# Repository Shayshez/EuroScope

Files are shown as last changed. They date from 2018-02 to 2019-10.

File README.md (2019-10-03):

# EuroScope MKII - DSO150 Eurorack Conversion Kit
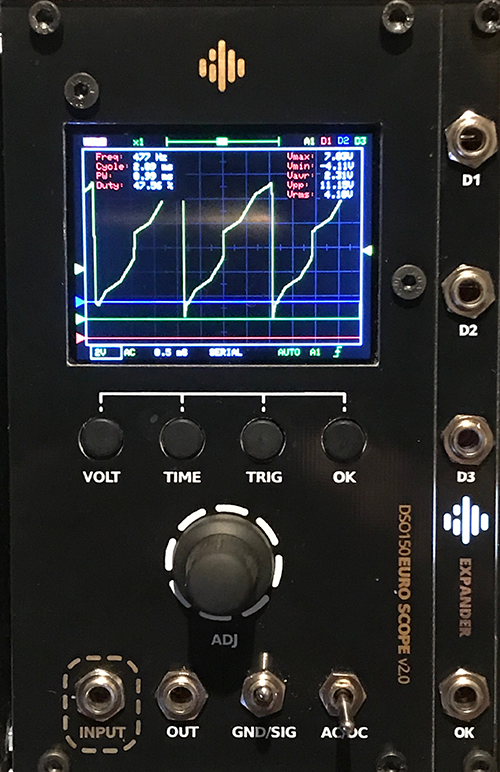
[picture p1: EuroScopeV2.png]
DSO150 EuroScope


[DSO 150](https://www.banggood.com/Orignal-JYE-Tech-DS0150-15001K-DSO-SHELL-DIY-Digital-Oscilloscope-Kit-With-Housing-p-1093865.html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) Is a cheap mini oscilloscope from JYE TECH.

This conversion kit lets you the ability to convert it to Eruorack module and contains two parts:

* 14 Hp Panel
* Conversion Board
* Optional: [Expander 2Hp PCB+Panel](https://pushermanproductions.com/product/plum-audio-dso150-mk2-oscilloscope-expander-2hp-pcb-panel/) - Provides 3 additional digital inputs (Will work only with [Open DSO 150](https://github.com/michar71/Open-DSO-150) Firmware), OK Botton trigger input and Trigger led.

This is an easy DIY project, just follow the [Build guide](EuroScope_mk2_v2.2-Build_Guide.pdf) (PDF File) I'll recommend to download it to your computer.
(You can find the BOM in the build guide).

* Assemblong Videos Playlist: https://www.youtube.com/watch?v=Akz4jSZyOQc&list=PL2KBIbSMnGOh_Mu7Z_c3bYFIhDCGHZpcL

___________________________________________________
## Alternative Firmware:
There is alternative firmware to DSO150 that add lots of new features, more info at:
[Open DSO 150](https://github.com/michar71/Open-DSO-150)
___________________________________________________
## Which is the right DSO150 DIY Kit?
I checked few sources for the DSO150 kits, only the ones that come from [Banggood](https://www.banggood.com/Orignal-JYE-Tech-DS0150-15001K-DSO-SHELL-DIY-Digital-Oscilloscope-Kit-With-Housing-p-1093865.html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) was original 2017 version.

Other versions was less accurate and with a lots of ground noises.
If you’re not buying the banggood version you need to find 2017 version and pay attention to (see picture):
1. Trimmers location.
2. Cut in the main PCB for trimmers access.
3. Only 3 electrolytic capacitors in the analog board (not 5).
4. Sticker with Barcode and Serial Number.
5. Silk screen that says it’s 2017 version... 

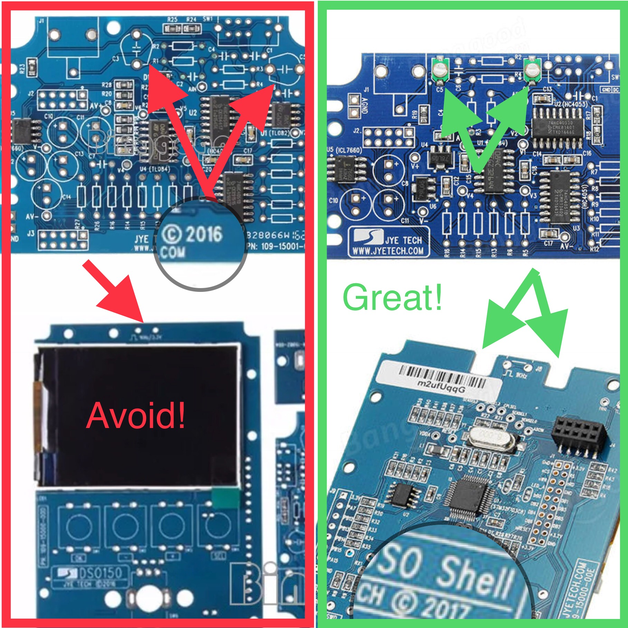
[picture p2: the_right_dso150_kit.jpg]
the right DSO150 DIY Kit


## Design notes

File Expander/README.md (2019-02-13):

# Expander For EuroScope

Adds additional Buffered inputs:
- 3 Digital Inputs D1, D2, D3 ([Open DSO 150](https://github.com/michar71/Open-DSO-150) Firmware is required).
- OK button trigger input.
- Also, brings the DSO150 Trigger led indicator to front.

### Expander BOM:

|Q|Part|Value|Reference|
|-|----|-----|---|
|1|Assembled EuroScope|Expander will work with all versions|[Pusherman](https://pushermanproductions.com/product/dso150-mk2-oscilloscope-eurorack-conversion-kit-14hp-pcb-panel/)|
|1|Expander PCB&Panel||[Pusherman](https://pushermanproductions.com/product/plum-audio-dso150-mk2-oscilloscope-expander-2hp-pcb-panel/)|
|4|Resistor 0603|100k|R1, R2, R3, R4|
|1|Resistor 0603|1K|R5 (For Led Brightness)|
|4|NPN Transistor| MMBT3904|T1, T2, T3, T4|
|1|LED 1206|Any colour you like...|LED1|
|4|Jack PJ398SM|"Thonkiconn"|J2, J3, J4, J5|
|1|Male Pin headers 2.54| 1 row of 7 Pins| J1|

**To connect between Boards:**

|Q|Part|Value|Reference|
|-|----|-----|---|
|1|Male Pin headers 2.54| 1 row of 8 Pins|**DSO150 Main Board:** J9 (For Connection with Expander)|
|1|Male Pin headers 2.54| 1 row of 4 Pins|**DSO150 Main Board:** J3 (SWD - To Update the Firmware)
|7|Feamle to Feamle Jumper Wire|To connect between Boards||
|1|Male to Male Jumper Wire|To connect between Boards|| 

**How To Build?**
1. Build the Expander... Solder all components in place and assemble the panel.
2. Connect the Expander:

|Expander J1|DSO 150|
|---|---|
|3.3V|3.3V @J9|
|PB13|PB13 @J9|
|PB14|PB14 @J9|
|PB15|PB15 @J9|
|GND|GND @J9|

Cut Male to Male Jumper wire into two parts and solder to DSO150:

|Expander J1|DSO 150|
|---|---|
|OK|Top Right Pin of OK Button|
|LED|Remove R14 and solder this wire to top pad of R14|

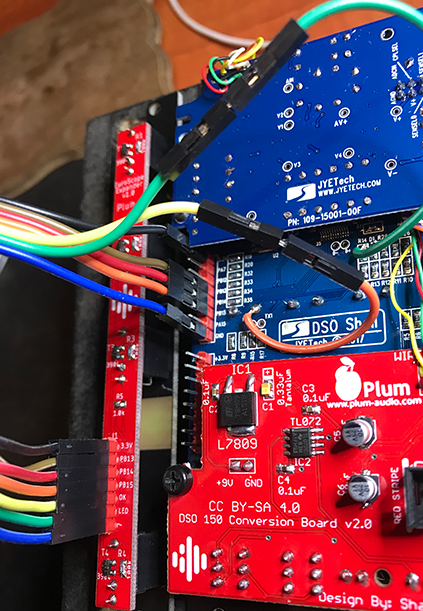
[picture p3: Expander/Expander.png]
Expander

___________________________________________________________________________
# Firmware Update:

I'm using ST-LINK V2 with ST-LINK Utility software on Windows Environment.
You can find hex file in this repo ([here](Firmware%20-%20Open%20DSO150)) 

Connect the programer to DSO150:

|ST-LINK JTAG Port|DSO 150 SWD Port|
|---|---|
|Pin 1|3.3V @J3|
|Pin 3|GND @J3|
|Pin 7|DIO @J3|
|Pin 9|CLK @J3|

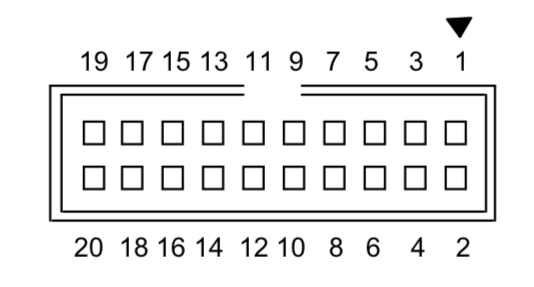
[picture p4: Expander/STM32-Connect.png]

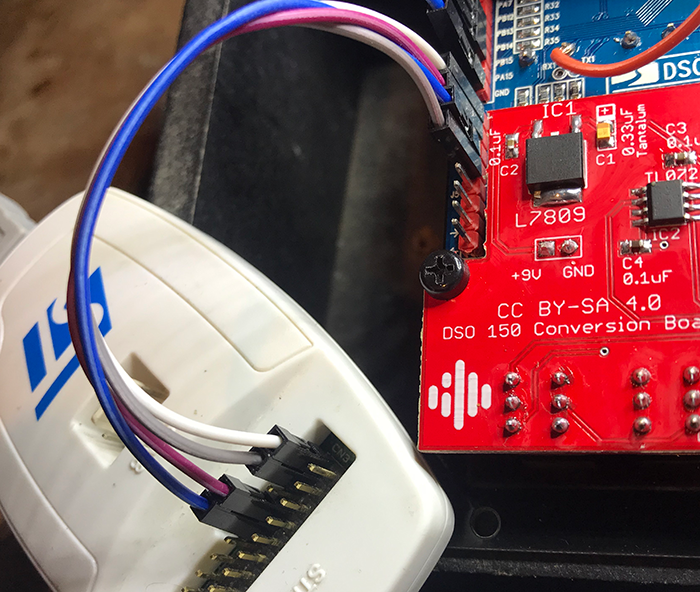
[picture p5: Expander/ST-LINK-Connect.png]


***For next steps you need to connect your EuroScope to power source.**

**With ST-LINK Utility Software:**
1. Go to Target->Settings and choose SWD Port, Frequency = 4.0 MHz, After you click "OK" the programer should connect to DSO150 automatically.
2. Go to Target->Program & Verify, Browse and select new firmware [hex file](Firmware%20-%20Open%20DSO150) and hit Start
3. After the Flash process finished, restart EuroScope and hold "OK" button during boot up.

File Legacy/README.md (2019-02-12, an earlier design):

# DSO150 Eurorack Conversion Kit
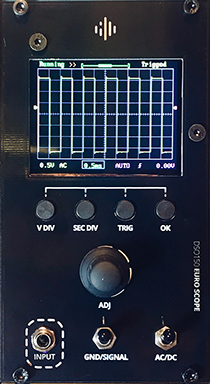
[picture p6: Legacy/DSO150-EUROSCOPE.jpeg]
DSO150 EuroScope


[DSO 150](https://www.banggood.com/Orignal-JYE-Tech-DS0150-15001K-DSO-SHELL-DIY-Digital-Oscilloscope-Kit-With-Housing-p-1093865.html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) Is a cheap mini oscilloscope from JYE TECH.

This conversion kit lets you the ability to convert it to Eruorack module and contains two parts:

* 14 Hp Panel
* Conversion Board

This is an easy DIY project, just follow the [Build guide](https://github.com/Shayshez/DSO150-Euro-Scope/blob/master/DSO-150-Eurorack-Conversion-Kit-v1.pdf).
___________________________________________________
## Bill Of Materials:
Q|Part/Value|Source
-|----------|------
1|DSO150 Eurorack panel|[Pusherman](https://pushermanproductions.com/product/dso150-oscilloscope-eurorack-conversion-kit-14hp-pcb-panel/)
1|DSO150 Conversion Board|[Pusherman](https://pushermanproductions.com/product/dso150-oscilloscope-eurorack-conversion-kit-14hp-pcb-panel/)
1|Original Dso150 (15001K) DIY KIT|[Banggood](https://www.banggood.com/Orignal-JYE-Tech-DS0150-15001K-DSO-SHELL-DIY-Digital-Oscilloscope-Kit-With-Housing-p-1093865.html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)
1|L7809CV – 9v Voltage Regulator|[Tayda](https://www.taydaelectronics.com/l7809cv-l7809-7809-voltage-regulator-ic-9v-1-5a.html)
1|0.33uF – Tantalum Capacitor|[Tayda](https://www.taydaelectronics.com/capacitors/tantalum-capacitors/0-33uf-50v-radial-tantalum-capacitor.html)
1|0.1uF – Ceramic Capacitor|[Tayda](https://www.taydaelectronics.com/capacitors/ceramic-disc-capacitors/10-x-0-1uf-50v-ceramic-disc-capacitor-pkg-of-10.html)
1|2X1 Male Pin Headers|[Tayda](https://www.taydaelectronics.com/connectors-sockets/pin-headers/40-pin-2-54-mm-single-row-pin-header-strip.html)
1|10 Pin Eurorack Power Socket|[Tayda](https://www.taydaelectronics.com/connectors-sockets/box-header-connectors/10-pin-box-header-connector-2-54mm.html)
2|3M - 6mm Standoffs (Spacers) + 2 3M Screws|[AliExpress](https://www.aliexpress.com/item/180Pcs-set-M3-L-6mm-M-F-Black-Spacing-Screw-Plastic-For-PCB-Motherboard-Fixed-Nylon/32834701711.html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,searchweb201602_1_10065_10068_10344_10342_10343_103)
2|3M – 12mm-16mm Black Screws|[AliExpress](https://www.aliexpress.com/item/Free-Shipping-100pcs-M3x8-mm-M3-8-mm-flat-head-countersunk-head-black-grade-10-9/32421673207.html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)
1|EC12E_SW Encoder|[Mouser](https://www.mouser.co.il/ProductDetail/858-EN11-HSM1BF20)
1|PJ301M-12 “Thonkiconn”|[Thonk](https://www.thonk.co.uk/shop/3-5mm-jacks/)
2|DPDT (ON-ON) Sub Miniature Toggle Switch|[Thonk](https://www.thonk.co.uk/shop/sub-mini-toggle-switches/)
1|Encoder Knob (Sifam Large Soft Encoder Knob – 12mm D-Shaft Illuminated)|[Thonk](https://www.thonk.co.uk/shop/sifam-soft-touch-encoder-knobs/)
8|10cm Wrapping Wires|

___________________________________________________
## Alternative Firmware:
There is alternative firmware to DSO150 that add lots of new features, more info at:
[Open DSO 150](https://github.com/michar71/Open-DSO-150)
___________________________________________________
## Which is the right DSO150 DIY Kit?
I checked few sources for the DSO150 kits, only the ones that come from [Banggood](https://www.banggood.com/Orignal-JYE-Tech-DS0150-15001K-DSO-SHELL-DIY-Digital-Oscilloscope-Kit-With-Housing-p-1093865.html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) was original 2017 version.

Other versions was less accurate and with a lots of ground noises.
If you’re not buying the banggood version you need to find 2017 version and pay attention to (see picture):
1. Trimmers location.
2. Cut in the main PCB for trimmers access.
3. Only 3 electrolytic capacitors in the analog board (not 5).
4. Sticker with Barcode and Serial Number.
5. Silk screen that says it’s 2017 version... 

the right DSO150 DIY Kit

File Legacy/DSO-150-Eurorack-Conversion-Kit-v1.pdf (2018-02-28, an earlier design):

Plum’s DSO 150 EuroScope Build Guide rev 1.0 Eurorack Version by Shay Shezifi
31.01.18

Jye Tech DSO 150
Eurorack Conversion Kit rev1.0

# Build Guide

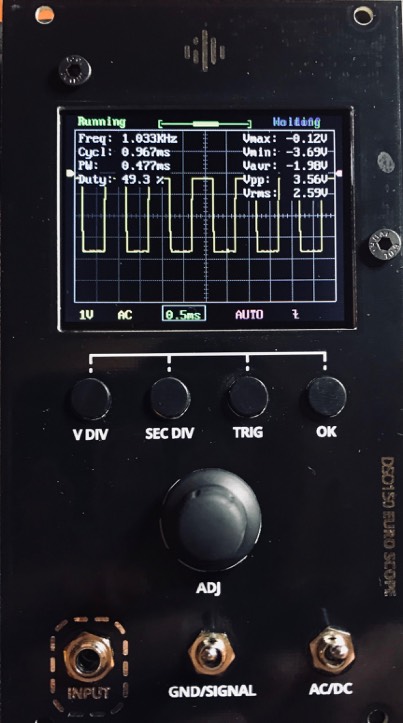
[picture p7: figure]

DSO 150 Is a cheap mini oscilloscope from JYE TECH.
This conversion kit lets you the ability to convert it to Eruorack module and contains two parts:
- 14 Hp Panel
- Conversion Board

This is an easy DIY project, just follow this instructions guide.

# Bill Of Materials

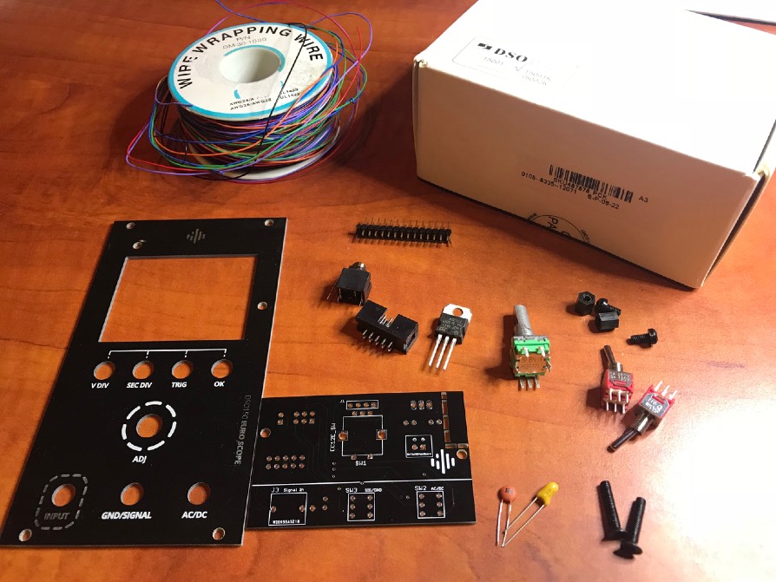
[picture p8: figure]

Q | Part/Value | Ref | Source | Notes
1 DSO150 Eurorack panel
1 DSO150 Conversion | Board
1 Original Dso150 | (15001K) DIY KIT | | Banggood (https://www.banggood.com/Orignal-JYE-Tech-DS0150-15001K-DSO-SHELL-DIY-Digital-Oscilloscope-Kit-With-Housing-p-1093865.html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) | There’s other places to buy this kit, but you need pay attention to: 1. buy only the original kit of jye tech version 2017. I’ve checked this source and it is the original kit. 2. buy the DIY Kit and not the assembled one.
1 L7809CV – 9v Voltage | Regulator | IC1 | Tayda (https://www.taydaelectronics.com/l7809cv-l7809-7809-voltage-regulator-ic-9v-1-5a.html)
1 0.33uF – Tantalum | Capacitor | | Tayda (https://www.taydaelectronics.com/capacitors/tantalum-capacitors/0-33uf-50v-radial-tantalum-capacitor.html) | !! Tantalum !! - Polarized Capacitor

Q | Part/Value | Ref | Source | Notes
1 0.1uF – Ceramic | Capacitor | | Tayda (https://www.taydaelectronics.com/capacitors/ceramic-disc-capacitors/10-x-0-1uf-50v-ceramic-disc-capacitor-pkg-of-10.html)
1 | 2X1 Male Pin Headers | | Tayda (https://www.taydaelectronics.com/connectors-sockets/pin-headers/40-pin-2-54-mm-single-row-pin-header-strip.html) | Cut 2 from row of 40 pins
1 10 Pin Eurorack Power | Socket | | Tayda (https://www.taydaelectronics.com/connectors-sockets/box-header-connectors/10-pin-box-header-connector-2-54mm.html) | Box Header Type
2 3M - 6mm Standoffs | (Spacers) + 2 3M Screws | | AliExpress (https://www.aliexpress.com/item/180Pcs-set-M3-L-6mm-M-F-Black-Spacing-Screw-Plastic-For-PCB-Motherboard-Fixed-Nylon/32834701711.html) | The Nylon/Plastic Type are better. To mount the conversion board to dso150 main board.
2 3M – 12mm-16mm Black | Screws | | AliExpress (https://www.aliexpress.com/item/Free-Shipping-100pcs-M3x8-mm-M3-8-mm-flat-head-countersunk-head-black-grade-10-9/32421673207.html) | To mount the panel to DSO150 mainboard and fix the screen position.
1 | EC12E_SW Encoder | SW1 | Mouser (https://www.mouser.co.il/ProductDetail/858-EN11-HSM1BF20)
1 PJ301M-12 | “Thonkiconn” | J3 | Thonk (https://www.thonk.co.uk/shop/3-5mm-jacks/)
2 DPDT (ON-ON) Sub | Miniature Toggle Switch | SW2, SW3 | Thonk (https://www.thonk.co.uk/shop/sub-mini-toggle-switches/)
1 | Encoder Knob | | Thonk (https://www.thonk.co.uk/shop/sifam-soft-touch-encoder-knobs/) | I used Sifam Large Soft Encoder Knob – 12mm (D-Shaft Illuminated)

8 10cm Wrapping Wires

# Phase 1: Assembling DSO 150 KIT

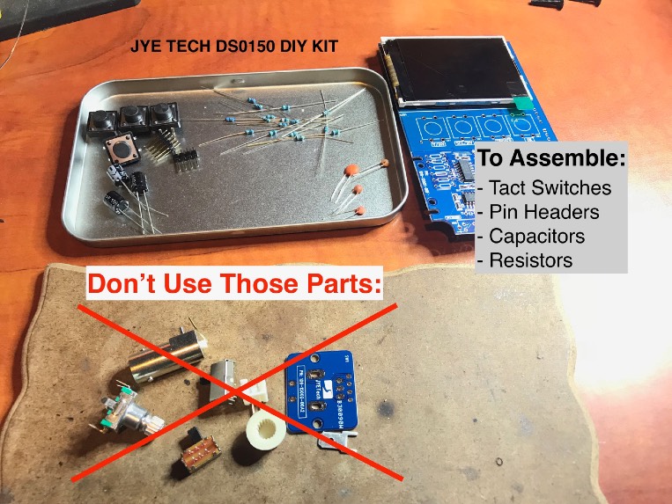
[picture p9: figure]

Basically, you need to follow the instructions in the user manual that come with your DSO150 DIY Kit BUT you need to do only the steps below (and skip the others):

1. In the mainboard (Marked as “Step 1”) You need to solder only the Tact Switches (Step 6) and desolder (or cut) the power socket.

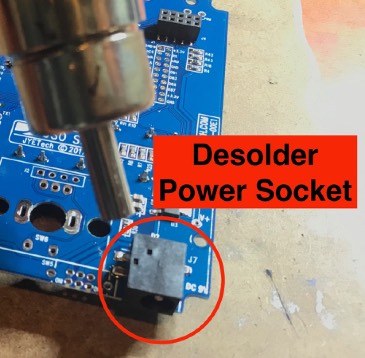
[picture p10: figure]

2. In the Analog Board (Marked as “Step 2”) You need to solder only the Resistors (Step 1), Capacitors (Steps 2 & 4) and the Pin-Header (Step 6).

# Phase 2: Assembling Conversion Board

1. Solder the Regulator, The Capacitors (Put attention to the Tantalum Capacitor polarity) and the power header

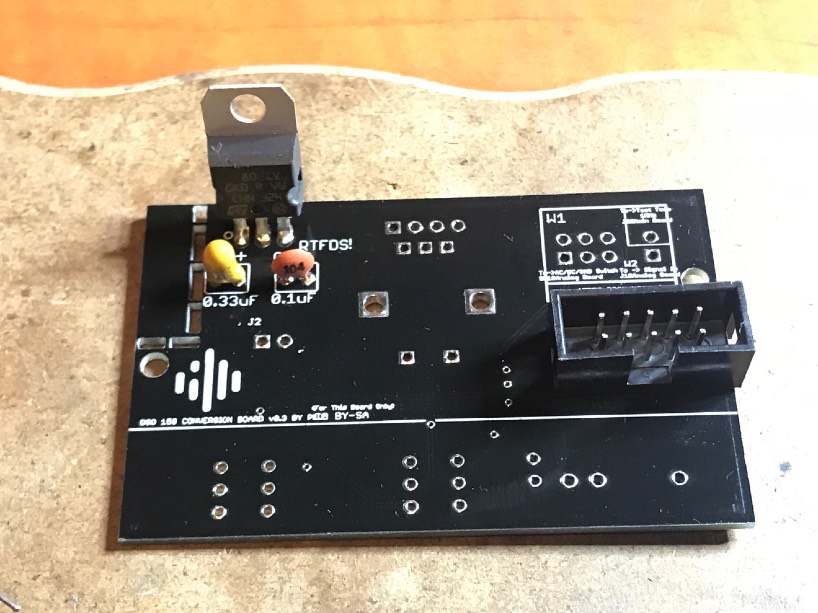
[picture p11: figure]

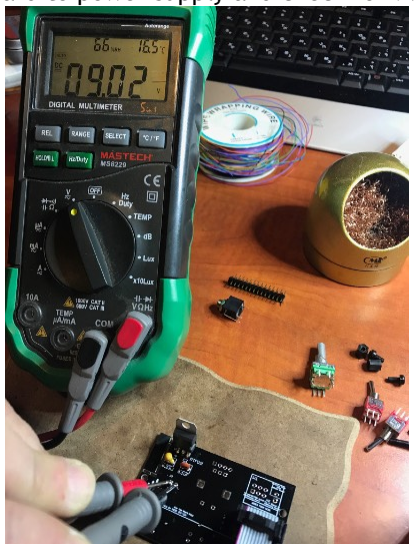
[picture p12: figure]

2. * Connect the board to power supply and check for 9v (+/- 10%) at J2
3. Prepare the encoder:

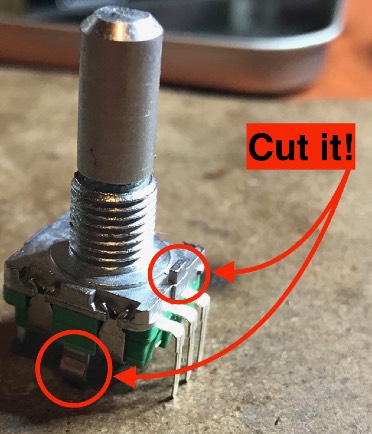
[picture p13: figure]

4. Put in place all interface parts (do not solder them yet)
- Encoder (SW1)
- Thonkiconn (J3)
- Toggle Switches (SW2, SW3)
5. Mount the conversion board to the DSO150 mainboard with 2 3M 6mm Standoffs spacers, Do Not forget to put in place the pin headers (J1, J2), If you need to expand the holes in the DSO150 mainboard you can rotate in them a sharp knife or scissors.

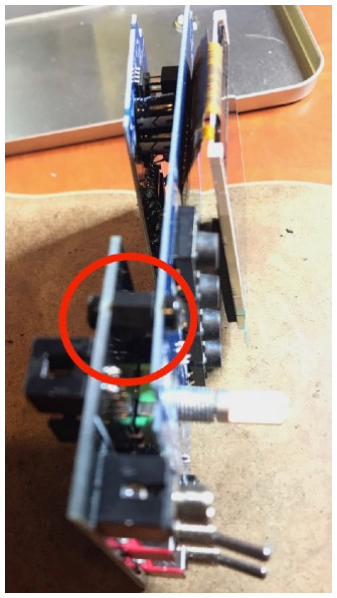
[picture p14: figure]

6. Solder the pin headers on both boards (J1, J2)

7. Wiring! :

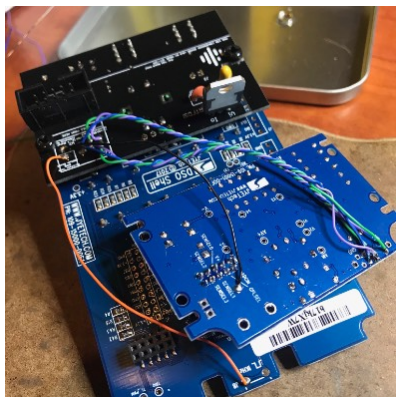
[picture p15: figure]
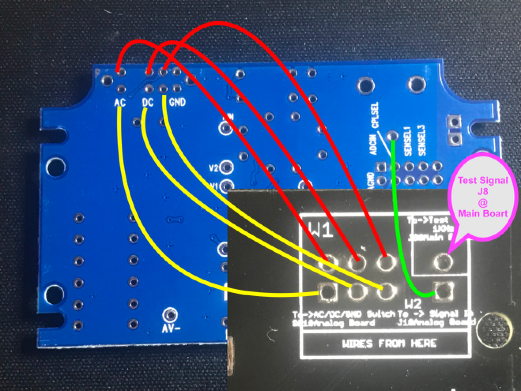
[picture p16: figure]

W1 – 6 Wires to SW1 @ DSO 150 analog board, from left to right:
- 2 wires of AC
- 2 Wires of DC
- 2 Wires for switches signal output, You do not need to wire the GND.

W2 – The square pad need to be wired to the signal input, It’s the lower hole of J1 (BNC Connector).

The round pad Need to be wired to test signal tone (J8 @ DSO 150 Main Board).

* Before you mount the panel. Its good time to adjust trimmers C3 and C5 (Step 5 @ DSO 150 user manual).
The test signal tone is normalized to the input jack, so you don’t need to plug anything to the audio input for calibration, just connect your module to a power supply and follow the DSO 150 manual calibrations instructions.

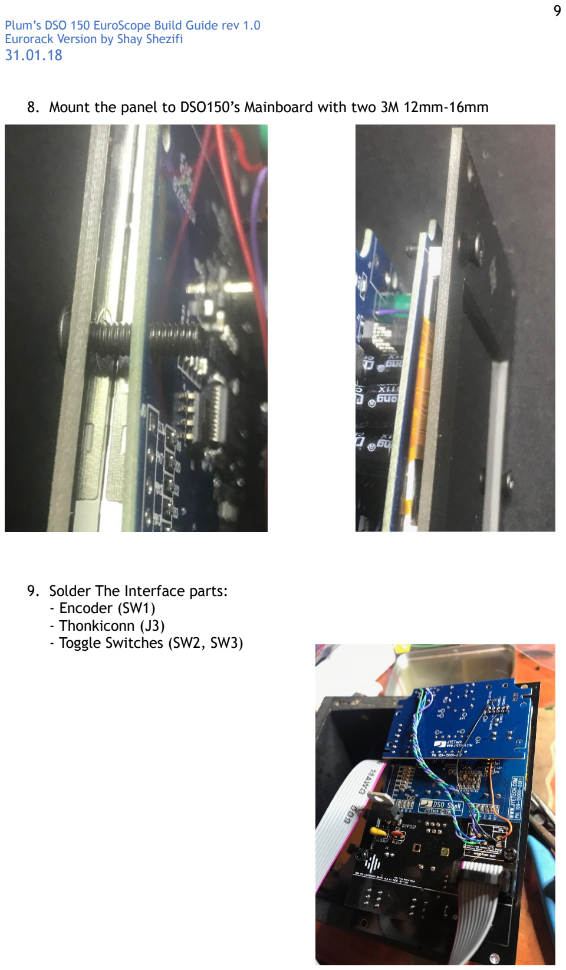
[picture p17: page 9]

8. Mount the panel to DSO150’s Mainboard with two 3M 12mm-16mm
9. Solder The Interface parts:
- Encoder (SW1)
- Thonkiconn (J3)
- Toggle Switches (SW2, SW3)

### Enjoy Your New DSO 150 EuroScope!

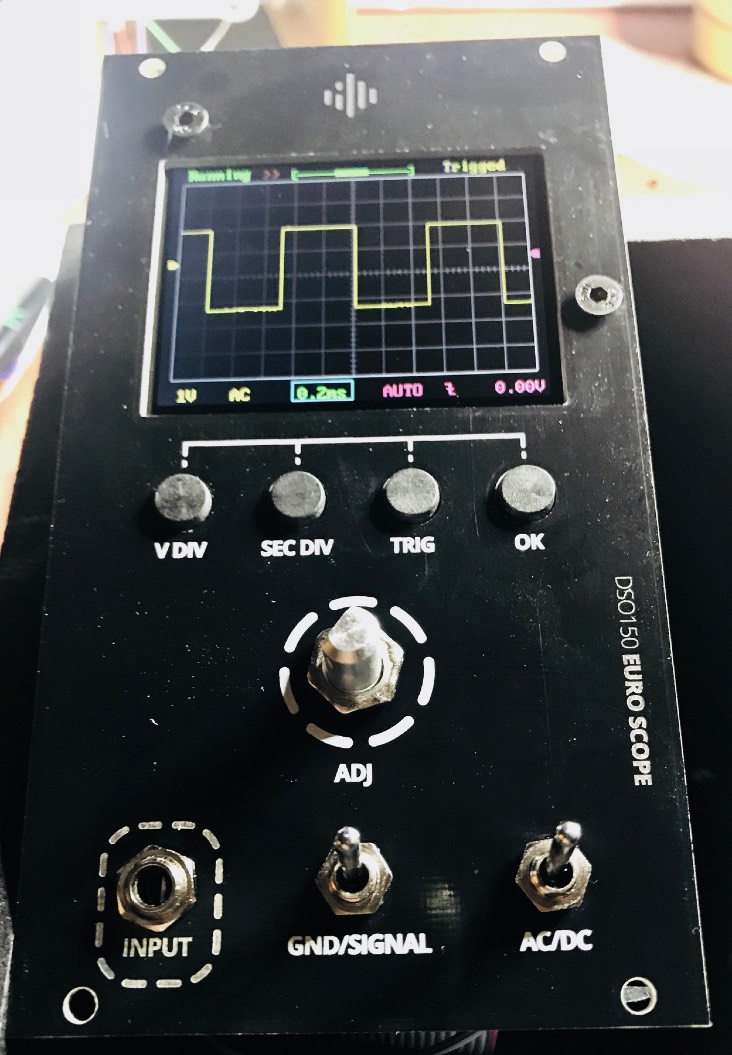
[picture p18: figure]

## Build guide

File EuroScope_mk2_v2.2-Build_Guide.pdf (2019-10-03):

Plum Audio - DSO 150 EuroScope v2.2 - Build Guide Deign by Shay Shezifi
04.10.19

Jye Tech DSO 150
Eurorack Conversion Kit MKII

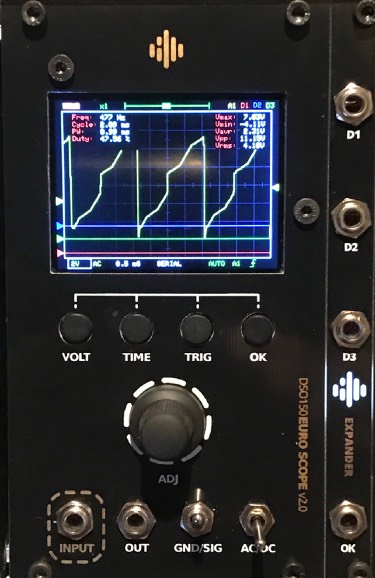
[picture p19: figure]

# Build Guide

DSO 150 Is a cheap mini oscilloscope from JYE TECH.
This conversion kit lets you the ability to convert it to Eruorack module and contains two parts:
- 14 Hp Panel
- Conversion Board
- Optional: Expander 2Hp PCB+Panel

This is an easy DIY project, just follow this instructions guide.

Assembling Video Playlist: https://www.youtube.com/watch?v=Akz4jSZyOQc&list=PL2KBIbSMnGOh_Mu7Z_c3bYFIhDCGHZpcL (https://www.youtube.com/watch?v=Akz4jSZyOQc&list=PL2KBIbSMnGOh_Mu7Z_c3bYFIhDCGHZpcL)

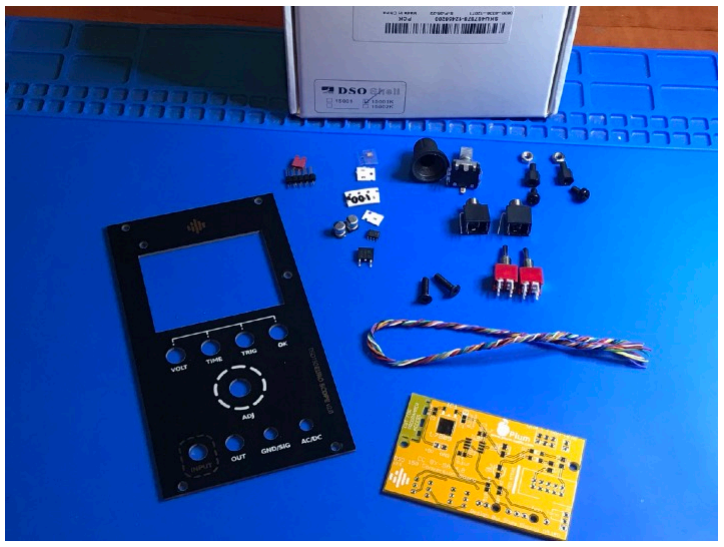
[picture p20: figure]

# Bill Of Materials

Q | Part/Value | Ref | Source | Notes
1 DSO150 Eurorack | panel mk2 | | Pusherman (https://pushermanproductions.com/product/dso150-mk2-oscilloscope-eurorack-conversion-kit-14hp-pcb-panel/)
1 DSO150 Conversion | Board mk2 | | Pusherman (https://pushermanproductions.com/product/dso150-mk2-oscilloscope-eurorack-conversion-kit-14hp-pcb-panel/)
1 Original Dso150 | (15001K) DIY KIT | | Banggood (https://www.banggood.com/Orignal-JYE-Tech-DS0150-15001K-DSO-SHELL-DIY-Digital-Oscilloscope-Kit-With-Housing-p-1093865.html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) | There’s other places to buy this kit, but you need pay attention to: 1. buy only the original kit of jye tech version 2017. I’ve checked this source and it is the original kit. 2. buy the DIY Kit and not the assembled one.
1 L7809CV – 9v Voltage | Regulator (SMD) | IC1 | Mouser (https://www.mouser.co.il/ProductDetail/STMicroelectronics/L78M09ABDT-TR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) | Mouser Part: 511-L78M09ABDT-TR (https://www.mouser.co.il/ProductDetail/STMicroelectronics/L78M09ABDT-TR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) (or AliExpress/eBay)
1 | TL072 SMD - SOIC8 | IC2 | Mouser (https://www.mouser.co.il/ProductDetail/Texas-Instruments/TL072CDR?qs=sGAEpiMZZMtYFXwiBRPs0zzUsTTH4TUq) Tayda (https://www.taydaelectronics.com/tl072-dual-operational-amplifier-j-fet-soic-8-tl072acdr.html)
2 | Diode 1N5819HW | D1,D2 | Mouser (https://www.mouser.co.il/ProductDetail/621-1N5819HW-F) AliExpress (https://www.aliexpress.com/item/Y120-100PCS-1n5819-Schottky-diode-SOD-123-diode-1n5819hw/32701520741.html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)
1 0.33uF – Tantalum | Capacitor (SMD 0805) | C1 | Mouser (https://www.mouser.co.il/ProductDetail/AVX/TAJR334K020RNJ?qs=sGAEpiMZZMuEN2agSAc2prc3ISwDBF1QwThknZSW4FI=) | Mouser Part: 581-TAJR334K020R (https://www.mouser.co.il/ProductDetail/AVX/TAJR334K020RNJ?qs=sGAEpiMZZMuEN2agSAc2prc3ISwDBF1QwThknZSW4FI=)

3 0.1uF – Ceramic | Capacitor <25v (SMD 0603/0805) | C2,C3, C4 | Tayda (https://www.taydaelectronics.com/capacitors/smd-ceramic-chip-capacitors/0805/100nf-50v-smd-ceramic-chip-capacitor.html) Mouser (https://www.mouser.co.il/ProductDetail/Wurth-Electronics/885012207098) AliExpress (https://www.aliexpress.com/item/500pcs-100nF-X7R-Error-10-50V-0805-SMD-Thick-Film-Chip-Multilayer-Ceramic-Capacitor-free-shipping/32812155708.html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)
2 10uF Electrolytic | Capacitor (SMD 4mm dia) <25v | | Mouser (https://www.mouser.co.il/ProductDetail/Panasonic/EEE-1EA100WR?qs=sGAEpiMZZMvwFf0viD3Y3WULMZcSm/DrrAUlodSiR3w=)
1 47uF Electrolytic | Capacitor (SMD 6.3mm dia) <25v | C7 | Mouser (https://www.mouser.co.il/ProductDetail/Panasonic/EEE-FK1V470P)
1 Resistor 4.7R (SMD | 1206) | R3 | Mouser (https://www.mouser.co.il/ProductDetail/Yageo/RC1206JR-074R7L?qs=sGAEpiMZZMu61qfTUdNhG5eFuApKbqVdPRBmOeertm0=)
1 Resistor 51R (SMD | 0603/0805) | R4 | Mouser (https://www.mouser.co.il/ProductDetail/Yageo/RC0805JR-7W51RL) Tayda (https://www.taydaelectronics.com/resistors/smd-chip-resistors/0805/50-x-smd-chip-resistors-51-ohm-1-8w-1-0805.html)
1 Resistor 10M (SMD | 0603/0805) | R2 | Mouser (https://www.mouser.co.il/ProductDetail/Vishay/CRCW080510M0FKEAC) Tayda (https://www.taydaelectronics.com/resistors/smd-chip-resistors/0805/50-x-smd-chip-resistors-10m-ohm-1-8w-1-0805.html)
1 | 3X1 Male Pin Headers | | Tayda (https://www.taydaelectronics.com/connectors-sockets/pin-headers/40-pin-2-54-mm-single-row-pin-header-strip.html) | Cut from row of 40 pins
1 | Jumper | | Tayda (https://www.taydaelectronics.com/mini-jumper-2-54mm-gold-plated-closed-cover.html)
1 10 Pin Eurorack | Power Socket | | Tayda (https://www.taydaelectronics.com/connectors-sockets/box-header-connectors/10-pin-box-header-connector-2-54mm.html) | Box Header Type
2 3M - 6mm Standoffs | (Spacers) + 2 3M Screws | | AliExpress (https://www.aliexpress.com/item/180Pcs-set-M3-L-6mm-M-F-Black-Spacing-Screw-Plastic-For-PCB-Motherboard-Fixed-Nylon/32834701711.html) | The Nylon/Plastic Type are better. To mount the conversion board to dso150 main board.
2 3M – 12mm-16mm | Black Screws | | AliExpress (https://www.aliexpress.com/item/Free-Shipping-100pcs-M3x8-mm-M3-8-mm-flat-head-countersunk-head-black-grade-10-9/32421673207.html) | To mount the panel to DSO150 mainboard and fix the screen position.
1 | PEC11L Encoder | SW6 (Main Board) | Mouser (https://www.mouser.co.il/ProductDetail/Bourns/PEC11L-4215F-S0015) | Mouser Part:652-PEC11L4215FS0015 (https://www.mouser.co.il/ProductDetail/Bourns/PEC11L-4215F-S0015) * 30 Detent / 15 PPR * SLIM Body SW6 on DSO150 Main Board.
2 PJ301M-12 | “Thonkiconn” | | Thonk (https://www.thonk.co.uk/shop/3-5mm-jacks/)
2 DPDT (ON-ON) Sub | Miniature Toggle Switch | SW2, SW3 | Thonk (https://www.thonk.co.uk/shop/sub-mini-toggle-switches/)
1 | Encoder Knob | | Thonk (https://www.thonk.co.uk/shop/sifam-soft-touch-encoder-knobs/) | Recommended - Sifam Large Soft Encoder Knob – 12mm (D-Shaft)

8 10cm Wrapping Wires

# Phase 1: Assembling DSO 150 KIT

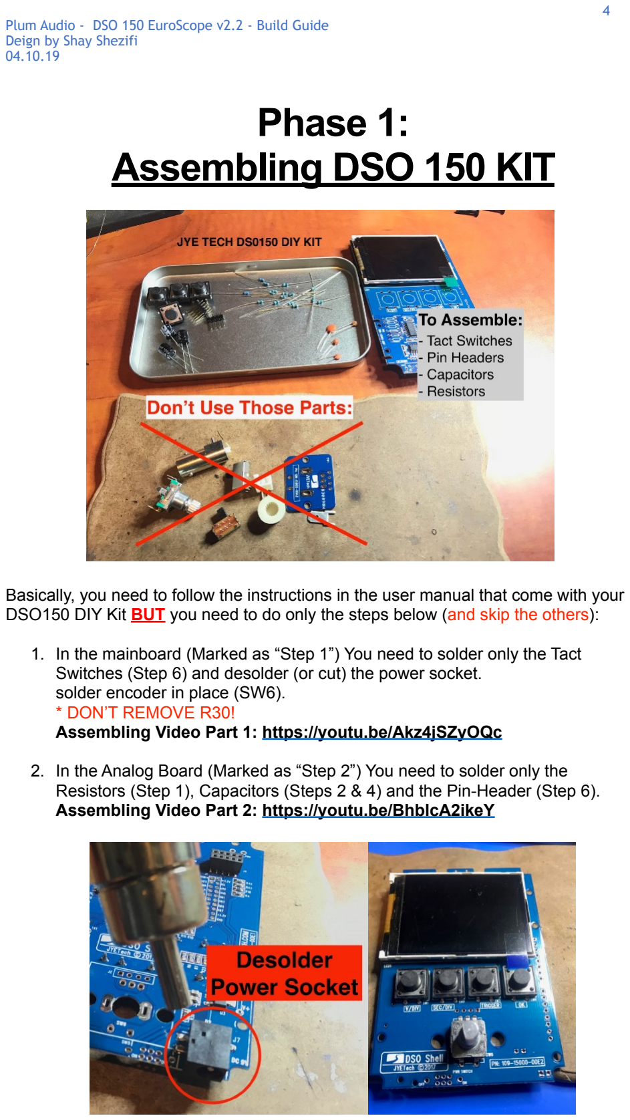
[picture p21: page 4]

Basically, you need to follow the instructions in the user manual that come with your DSO150 DIY Kit BUT you need to do only the steps below (and skip the others):

1. In the mainboard (Marked as “Step 1”) You need to solder only the Tact Switches (Step 6) and desolder (or cut) the power socket.
solder encoder in place (SW6).
* DON’T REMOVE R30!
Assembling Video Part 1: https://youtu.be/Akz4jSZyOQc
2. In the Analog Board (Marked as “Step 2”) You need to solder only the Resistors (Step 1), Capacitors (Steps 2 & 4) and the Pin-Header (Step 6). Assembling Video Part 2: https://youtu.be/BhblcA2ikeY

# Phase 2: Assembling Conversion Board

Assembling Video Part 3: https://youtu.be/UtAiYVECAHI

1. Solder all conversion board components (Regulator, Capacitors, Resistors, Opamp, Diodes, Power Header, 3 Pin headers), Short with jumper 2 top pins.

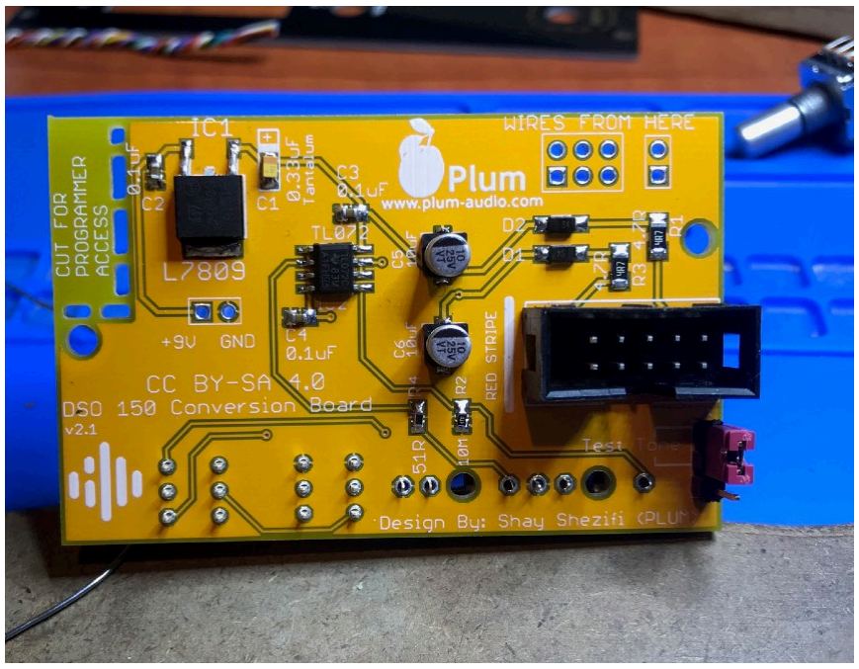
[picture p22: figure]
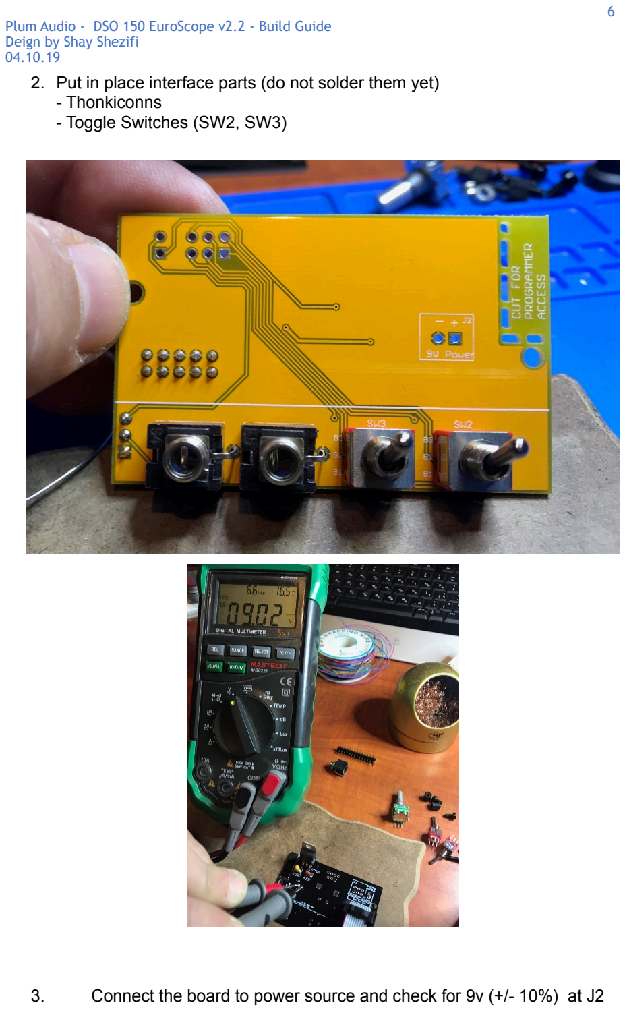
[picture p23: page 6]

2. Put in place interface parts (do not solder them yet)
- Thonkiconns
- Toggle Switches (SW2, SW3)
3. Connect the board to power source and check for 9v (+/- 10%) at J2

# Phase 3: Assembling all together

Assembling Video Part 4: https://youtu.be/_hivlbCN2zs

1. Wiring!

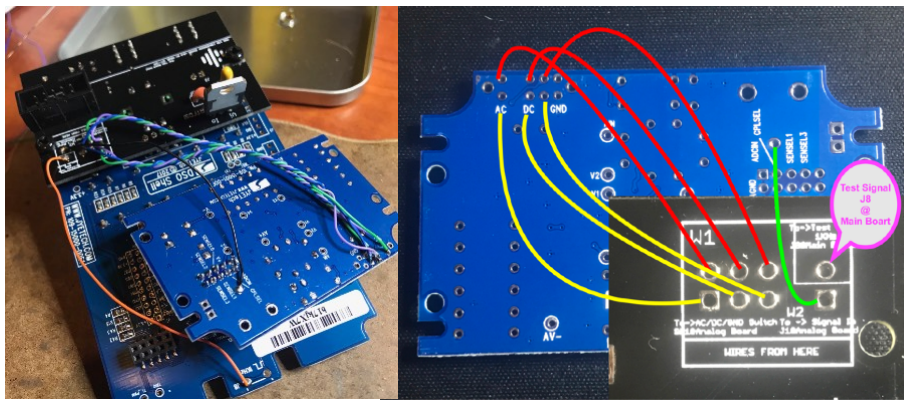
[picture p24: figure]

W1 – 6 Wires to SW1 @ DSO 150 analog board, from left to right:
- 2 wires of AC
- 2 Wires of DC
- 2 Wires for switches signal output, You do not need to wire the GND.

W2 – The square pad need to be wired to the signal input, It’s the lower hole of J1 (BNC Connector).

The round pad Need to be wired to test signal tone (J8 @ DSO 150 Main Board).

2. Mount the conversion board to the DSO150 mainboard with 2 3M 6mm Standoffs spacers, If you need to expand the holes in the DSO150 mainboard you can rotate in them a sharp knife or scissors.
Do Not forget to put in place the pin headers (J2)

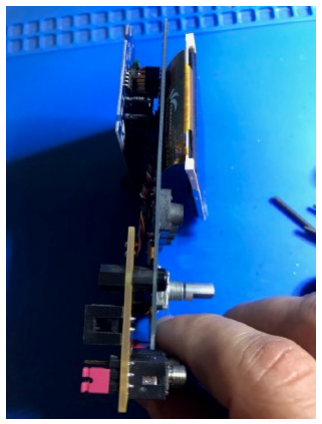
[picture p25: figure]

3. Solder J2 pin headers on both boards

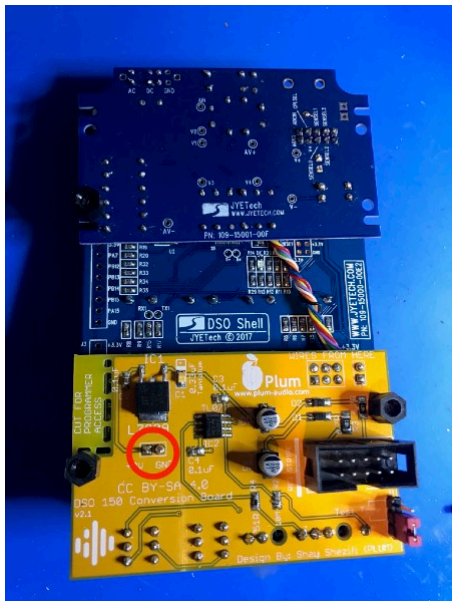
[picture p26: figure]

4. Before you mount the panel It’s good time to adjust trimmers C3 and C5 (Step 5 @ DSO 150 user manual).
The test signal tone is normalised to the input jack if the jumper set to “Test Tone”, so you don’t need to plug anything to the audio input for calibration, just connect your module to a power supply and follow the DSO 150 manual calibrations instructions (after calibration you can move the jumper to bottom position).

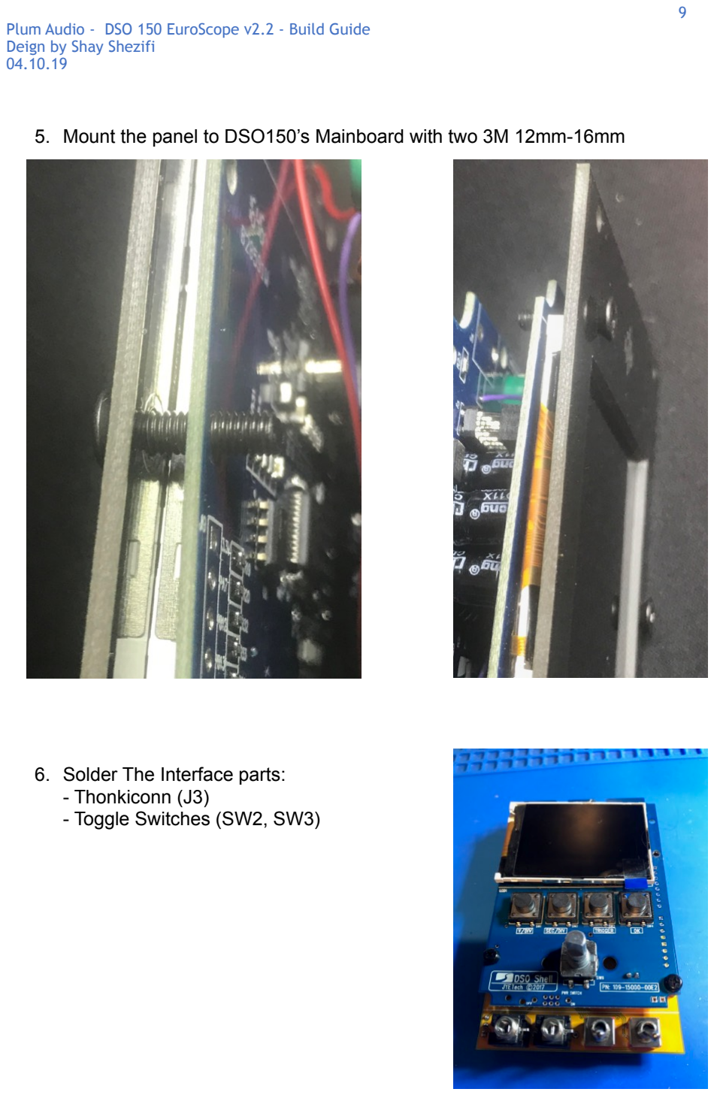
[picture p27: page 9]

5. Mount the panel to DSO150’s Mainboard with two 3M 12mm-16mm
6. Solder The Interface parts:
- Thonkiconn (J3)
- Toggle Switches (SW2, SW3)

## Enjoy Your New DSO 150 EuroScope v2.0!

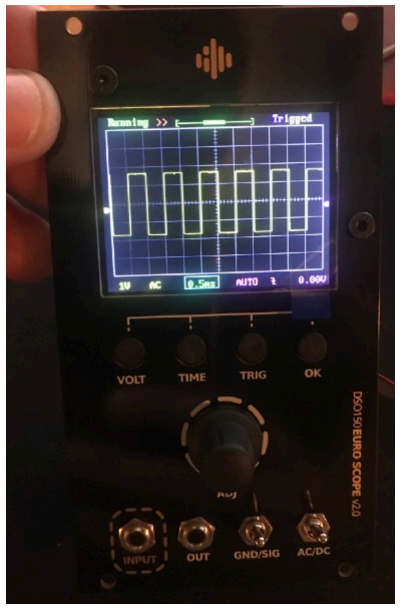
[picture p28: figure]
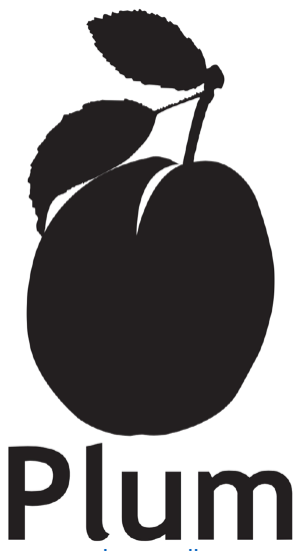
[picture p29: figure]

www.plum-audio.com

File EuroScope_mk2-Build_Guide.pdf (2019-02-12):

Plum Audio - DSO 150 EuroScope v2.0 - Build Guide Deign by Shay Shezifi
10.02.19

Jye Tech DSO 150
Eurorack Conversion Kit MKII


# Build Guide

DSO 150 Is a cheap mini oscilloscope from JYE TECH.
This conversion kit lets you the ability to convert it to Eruorack module and contains two parts:
- 14 Hp Panel
- Conversion Board
- Optional: Expander 2Hp PCB+Panel

This is an easy DIY project, just follow this instructions guide.

Assembling Video Playlist: https://www.youtube.com/watch?v=Akz4jSZyOQc&list=PL2KBIbSMnGOh_Mu7Z_c3bYFIhDCGHZpcL (https://www.youtube.com/watch?v=Akz4jSZyOQc&list=PL2KBIbSMnGOh_Mu7Z_c3bYFIhDCGHZpcL)

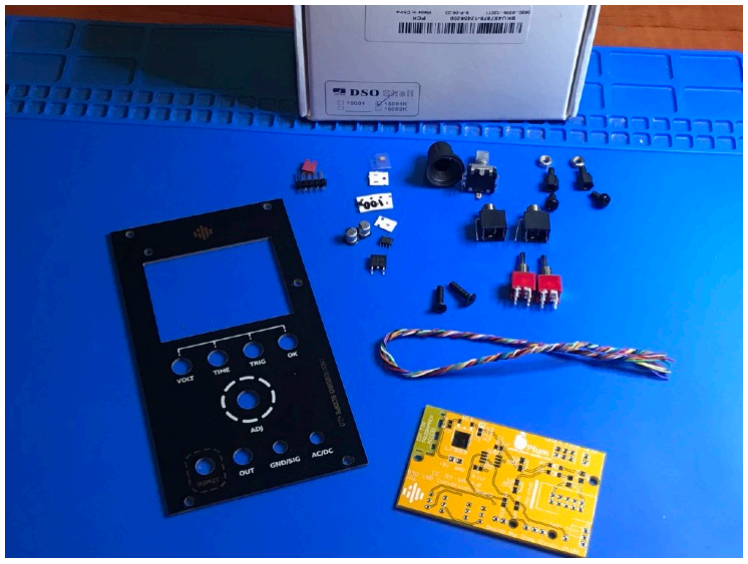
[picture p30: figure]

# Bill Of Materials

Q | Part/Value | Ref | Source | Notes
1 DSO150 Eurorack | panel mk2 | | Pusherman (https://pushermanproductions.com/product/dso150-mk2-oscilloscope-eurorack-conversion-kit-14hp-pcb-panel/)
1 DSO150 Conversion | Board mk2 | | Pusherman (https://pushermanproductions.com/product/dso150-mk2-oscilloscope-eurorack-conversion-kit-14hp-pcb-panel/)
1 Original Dso150 | (15001K) DIY KIT | | Banggood (https://www.banggood.com/Orignal-JYE-Tech-DS0150-15001K-DSO-SHELL-DIY-Digital-Oscilloscope-Kit-With-Housing-p-1093865.html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) | There’s other places to buy this kit, but you need pay attention to: 1. buy only the original kit of jye tech version 2017. I’ve checked this source and it is the original kit. 2. buy the DIY Kit and not the assembled one.
1 L7809CV – 9v Voltage | Regulator (SMD) | IC1 | Mouser (https://www.mouser.co.il/ProductDetail/STMicroelectronics/L78M09ABDT-TR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) | Mouser Part: 511-L78M09ABDT-TR (https://www.mouser.co.il/ProductDetail/STMicroelectronics/L78M09ABDT-TR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) (or AliExpress/eBay)
1 | TL072 SMD - SOIC8 | IC2 | Mouser (https://www.mouser.co.il/ProductDetail/Texas-Instruments/TL072CDR?qs=sGAEpiMZZMtYFXwiBRPs0zzUsTTH4TUq) Tayda (https://www.taydaelectronics.com/tl072-dual-operational-amplifier-j-fet-soic-8-tl072acdr.html)
2 | Diode 1N5819HW | D1,D2 | Mouser (https://www.mouser.co.il/ProductDetail/621-1N5819HW-F) AliExpress (https://www.aliexpress.com/item/Y120-100PCS-1n5819-Schottky-diode-SOD-123-diode-1n5819hw/32701520741.html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)

1 0.33uF – Tantalum | Capacitor (SMD 0805) | C1 | Mouser (https://www.mouser.co.il/ProductDetail/AVX/TAJR334K020RNJ?qs=sGAEpiMZZMuEN2agSAc2prc3ISwDBF1QwThknZSW4FI=) | Mouser Part: 581-TAJR334K020R (https://www.mouser.co.il/ProductDetail/AVX/TAJR334K020RNJ?qs=sGAEpiMZZMuEN2agSAc2prc3ISwDBF1QwThknZSW4FI=)
3 0.1uF – Ceramic | Capacitor <25v (SMD 0603/0805) | C2,C3, C4 | Tayda (https://www.taydaelectronics.com/capacitors/smd-ceramic-chip-capacitors/0805/100nf-50v-smd-ceramic-chip-capacitor.html) Mouser (https://www.mouser.co.il/ProductDetail/Wurth-Electronics/885012207098) AliExpress (https://www.aliexpress.com/item/500pcs-100nF-X7R-Error-10-50V-0805-SMD-Thick-Film-Chip-Multilayer-Ceramic-Capacitor-free-shipping/32812155708.html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)
2 10uF Electrolytic | Capacitor (SMD 4mm dia) <25v | | Mouser (https://www.mouser.co.il/ProductDetail/Panasonic/EEE-1EA100WR?qs=sGAEpiMZZMvwFf0viD3Y3WULMZcSm/DrrAUlodSiR3w=)
2 Resistor 4.7R (SMD | 1206) | R1, R3 | Mouser (https://www.mouser.co.il/ProductDetail/Yageo/RC1206JR-074R7L?qs=sGAEpiMZZMu61qfTUdNhG5eFuApKbqVdPRBmOeertm0=)
1 Resistor 51R (SMD | 0603/0805) | R4 | Mouser (https://www.mouser.co.il/ProductDetail/Yageo/RC0805JR-7W51RL) Tayda (https://www.taydaelectronics.com/resistors/smd-chip-resistors/0805/50-x-smd-chip-resistors-51-ohm-1-8w-1-0805.html)
1 Resistor 10M (SMD | 0603/0805) | R2 | Mouser (https://www.mouser.co.il/ProductDetail/Vishay/CRCW080510M0FKEAC) Tayda (https://www.taydaelectronics.com/resistors/smd-chip-resistors/0805/50-x-smd-chip-resistors-10m-ohm-1-8w-1-0805.html)
1 | 3X1 Male Pin Headers | | Tayda (https://www.taydaelectronics.com/connectors-sockets/pin-headers/40-pin-2-54-mm-single-row-pin-header-strip.html) | Cut from row of 40 pins
1 | Jumper | | Tayda (https://www.taydaelectronics.com/mini-jumper-2-54mm-gold-plated-closed-cover.html)
1 10 Pin Eurorack | Power Socket | | Tayda (https://www.taydaelectronics.com/connectors-sockets/box-header-connectors/10-pin-box-header-connector-2-54mm.html) | Box Header Type
2 3M - 6mm Standoffs | (Spacers) + 2 3M Screws | | AliExpress (https://www.aliexpress.com/item/180Pcs-set-M3-L-6mm-M-F-Black-Spacing-Screw-Plastic-For-PCB-Motherboard-Fixed-Nylon/32834701711.html) | The Nylon/Plastic Type are better. To mount the conversion board to dso150 main board.
2 3M – 12mm-16mm | Black Screws | | AliExpress (https://www.aliexpress.com/item/Free-Shipping-100pcs-M3x8-mm-M3-8-mm-flat-head-countersunk-head-black-grade-10-9/32421673207.html) | To mount the panel to DSO150 mainboard and fix the screen position.
1 | PEC11L Encoder | SW6 (Main Board) | Mouser (https://www.mouser.co.il/ProductDetail/Bourns/PEC11L-4215F-S0015) | Mouser Part:652-PEC11L4215FS0015 (https://www.mouser.co.il/ProductDetail/Bourns/PEC11L-4215F-S0015) * 30 Detent / 15 PPR * SLIM Body SW6 on DSO150 Main Board.
2 PJ301M-12 | “Thonkiconn” | | Thonk (https://www.thonk.co.uk/shop/3-5mm-jacks/)
2 DPDT (ON-ON) Sub | Miniature Toggle Switch | SW2, SW3 | Thonk (https://www.thonk.co.uk/shop/sub-mini-toggle-switches/)
1 | Encoder Knob | | Thonk (https://www.thonk.co.uk/shop/sifam-soft-touch-encoder-knobs/) | Recommended - Sifam Large Soft Encoder Knob – 12mm (D-Shaft)

8 10cm Wrapping Wires

# Phase 1: Assembling DSO 150 KIT

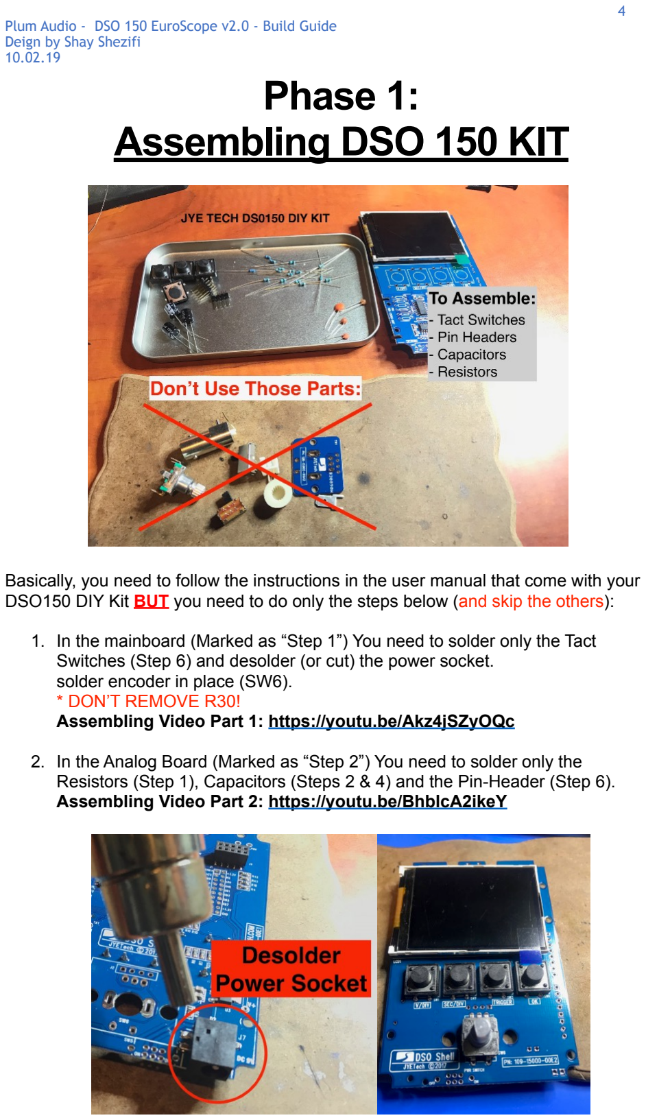
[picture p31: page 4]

Basically, you need to follow the instructions in the user manual that come with your DSO150 DIY Kit BUT you need to do only the steps below (and skip the others):

1. In the mainboard (Marked as “Step 1”) You need to solder only the Tact Switches (Step 6) and desolder (or cut) the power socket.
solder encoder in place (SW6).
* DON’T REMOVE R30!
Assembling Video Part 1: https://youtu.be/Akz4jSZyOQc
2. In the Analog Board (Marked as “Step 2”) You need to solder only the Resistors (Step 1), Capacitors (Steps 2 & 4) and the Pin-Header (Step 6). Assembling Video Part 2: https://youtu.be/BhblcA2ikeY

# Phase 2: Assembling Conversion Board

Assembling Video Part 3: https://youtu.be/UtAiYVECAHI

1. Solder all conversion board components (Regulator, Capacitors, Resistors, Opamp, Diodes, Power Header, 3 Pin headers), Short with jumper 2 top pins.

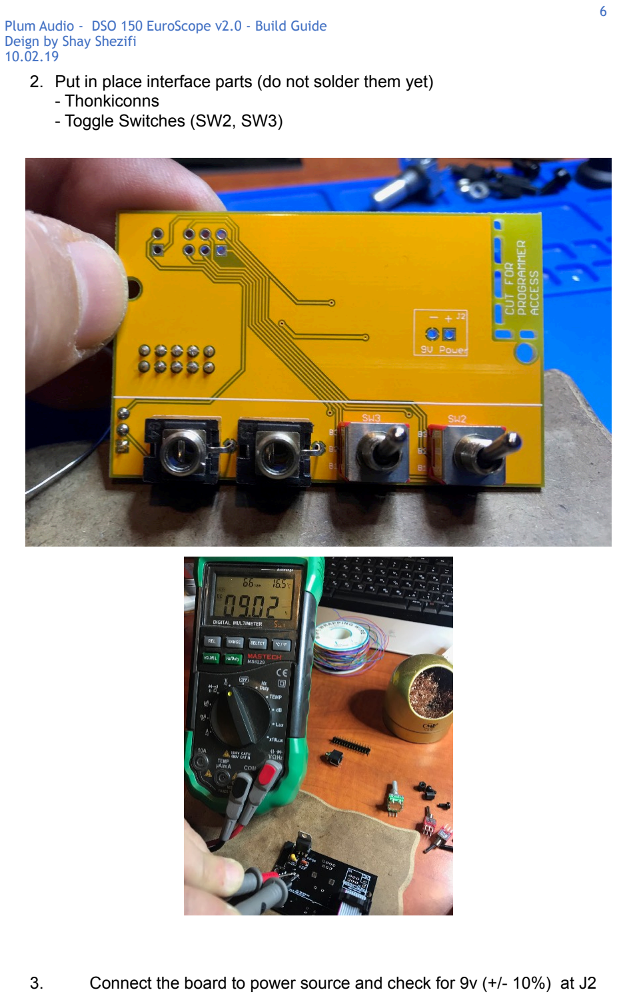
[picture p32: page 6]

2. Put in place interface parts (do not solder them yet)
- Thonkiconns
- Toggle Switches (SW2, SW3)
3. Connect the board to power source and check for 9v (+/- 10%) at J2

# Phase 3: Assembling all together

Assembling Video Part 4: https://youtu.be/_hivlbCN2zs

1. Wiring!

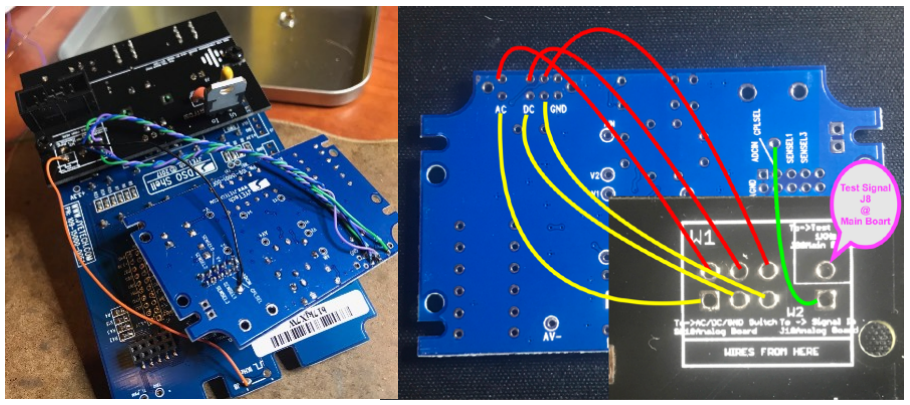
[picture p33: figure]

W1 – 6 Wires to SW1 @ DSO 150 analog board, from left to right:
- 2 wires of AC
- 2 Wires of DC
- 2 Wires for switches signal output, You do not need to wire the GND.

W2 – The square pad need to be wired to the signal input, It’s the lower hole of J1 (BNC Connector).

The round pad Need to be wired to test signal tone (J8 @ DSO 150 Main Board).

2. Mount the conversion board to the DSO150 mainboard with 2 3M 6mm Standoffs spacers, If you need to expand the holes in the DSO150 mainboard you can rotate in them a sharp knife or scissors.
Do Not forget to put in place the pin headers (J2)


3. Solder J2 pin headers on both boards


4. Before you mount the panel It’s good time to adjust trimmers C3 and C5 (Step 5 @ DSO 150 user manual).
The test signal tone is normalised to the input jack if the jumper set to “Test Tone”, so you don’t need to plug anything to the audio input for calibration, just connect your module to a power supply and follow the DSO 150 manual calibrations instructions (after calibration you can move the jumper to bottom position).

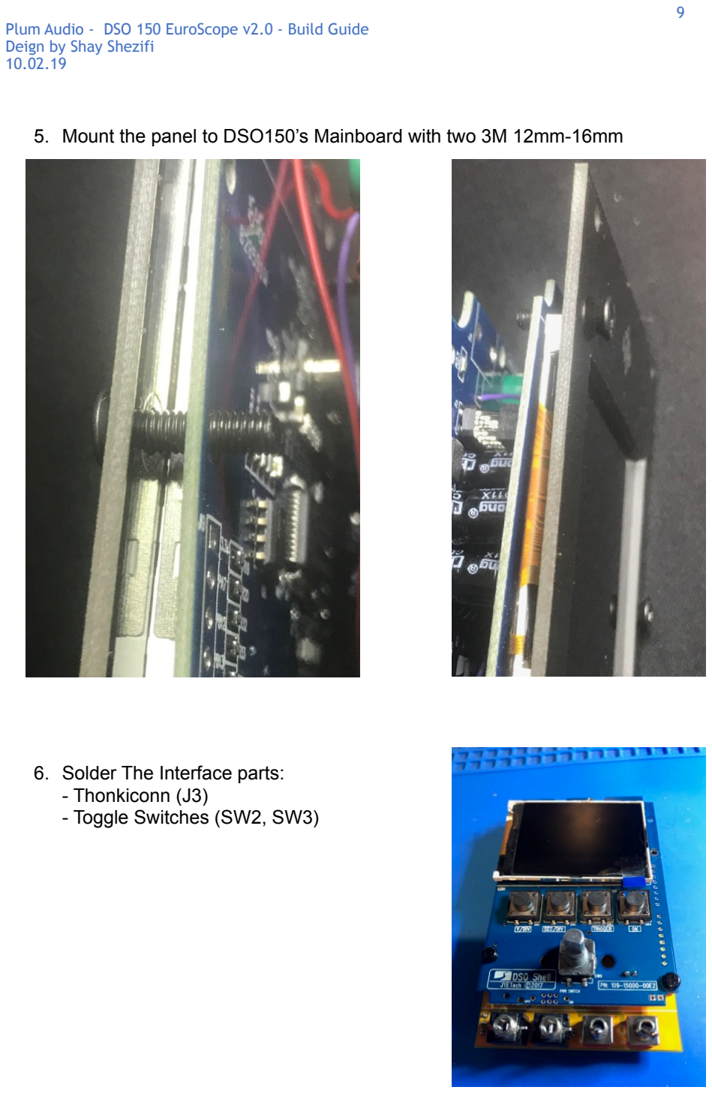
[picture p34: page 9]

5. Mount the panel to DSO150’s Mainboard with two 3M 12mm-16mm
6. Solder The Interface parts:
- Thonkiconn (J3)
- Toggle Switches (SW2, SW3)

## Enjoy Your New DSO 150 EuroScope v2.0!

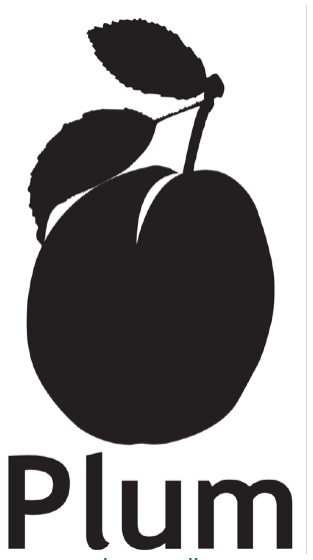
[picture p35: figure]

www.plum-audio.com

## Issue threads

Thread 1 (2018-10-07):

EC12E_SW Encoder & Mouser

GRK-Astronomer, 2018-10-07:
Hi Shay,

I noticed the Encoder listeec in the BOM for the DSO 150 Euro Scope is definitely no specific enough to identify which of the Mouser Part Numbers match what needs to be purchased.  EC12E_SW is not a part number on Mouser or with Alps that makes the encoder needed.

Could tou be more specific on the exact part required.  I have ordered all parts for three of the DSO 150 Eurorack modules except for the encoder.

Thanks,

Glenn

GRK-Astronomer, 2018-10-07:
Shay is working on this.  DSO150 needs to have an encoder with 30 detents.  Current one only has 20

Shayshez, 2018-10-13:
The Bourns 30 Detent encoder is perfect.
it is possible to solder it directly to DSO-150 Main board in this case it's better to use the 15mm shaft version:
https://www.mouser.co.il/ProductDetail/Bourns/PEC11L-4215F-S0015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

GRK-Astronomer, 2018-10-13:
Hi Shay,

Thanks for the “construction” note regarding the Bourns encoder.  I will order the three that I need today.  The MA faceplate and interface board for one of the DSOs arrived yesterday and I am holding off on ordering the other two.  The remainder if the parts and the DSO-Kits were ordered already.  I imagine the DSO kits take awhile in the mail.

BTW, I liked the u_T and o_C combined 1U module idea.  I have them in separate 3U modules; but, have not had a lot of time to “explore” them yet.  Probably would have been better to look at them as Utility modules place into 1U format to begin with.  So, when things become available, I will probably get yours and set the others aside for awhile.

I want to say, THANK YOU, for the help you have been!

Sent from Glenn’s iPad

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

GRK-Astronomer, 2018-10-16:
Closing the issue.

Closed 2018-10-16.

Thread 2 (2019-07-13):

Conversion board components burnt

the-lorn-teat-flag, 2019-07-13:
Hi Shayshez,

First thank you for your excellent modules :)

I've bought the EuroScope panel + PCB kit from Pusherman.

When I first powered it up, some components burnt.
I think R1 and C1 are dead.

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

Is there something you can see on this picture?

Thanks,
Florent

the-lorn-teat-flag, 2019-10-05:
I solved the problem by replacing all the small components ;)

Closed 2019-10-05.

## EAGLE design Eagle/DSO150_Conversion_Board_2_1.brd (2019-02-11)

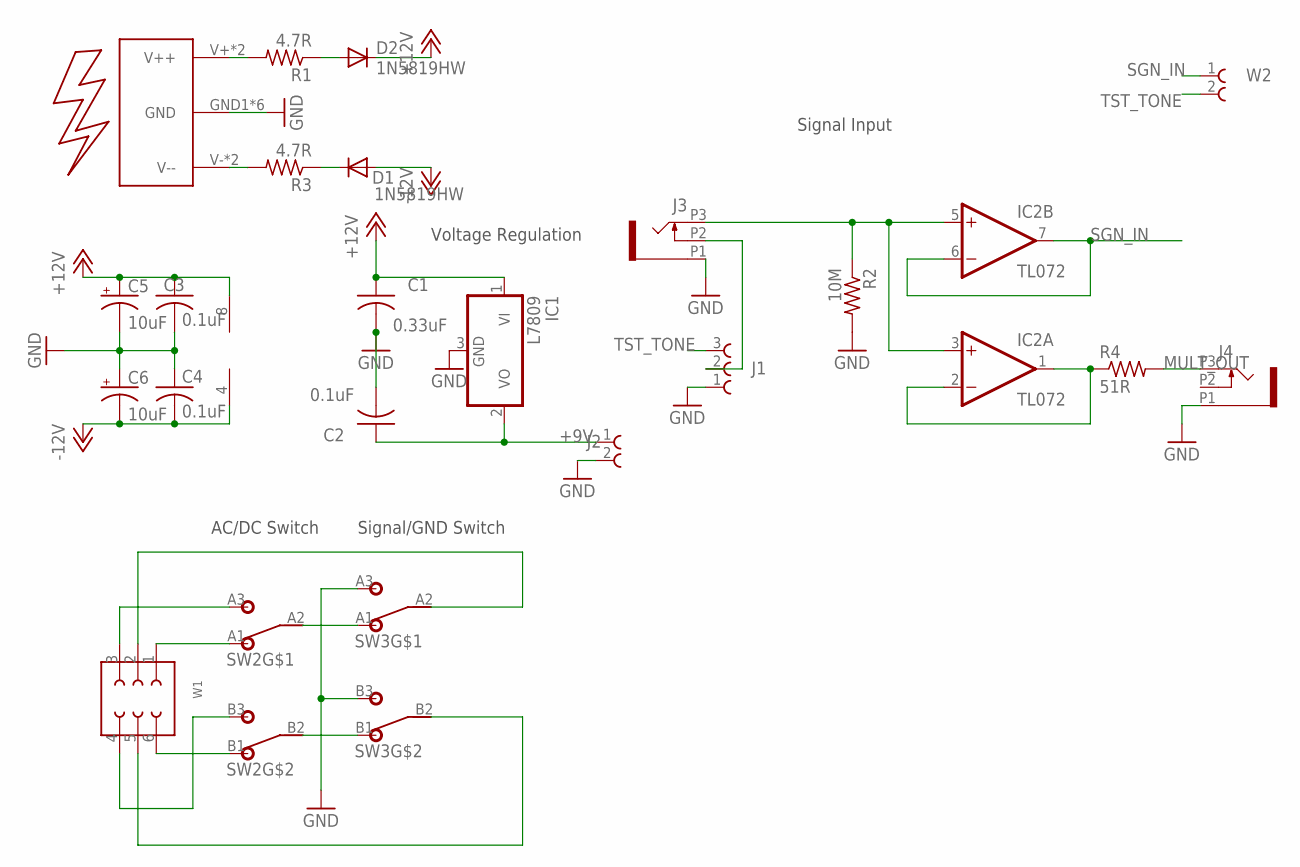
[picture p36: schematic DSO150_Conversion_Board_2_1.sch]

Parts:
C1: 0.33uF; C0805
C2, C3, C4: 0.1uF; C0805
C5, C6: 10uF; PANASONIC_B
D1, D2: 1N5819HW; DIODE_SOD123
IC1: L7809; TO252
IC2: TL072; SO08
J1: 61300311121
J2: 61300211121
J3, J4: OG-PJ301_PJ301_THONKICONN7; OG-PJ301_WQP_PJ_301M7
R1, R3: 4.7R; R1206
R2: 10M; R0805
R4: 51R; R0805
SW2, SW3: SUBDPDT; SUBMINIDPDT
U$2: EURO_POWER2
W1: 61300621121
W2: 61300211121

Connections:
+9V: C2.1, IC1.2 (VO), J2.1
+12V: C1.1, C3.1, C5.+, D2.C, IC1.1 (VI), IC2.8 (V+)
-12V: C4.2, C6.-, D1.A, IC2.4 (V-)
GND: C1.2, C2.2, C3.2, C4.1, C5.-, C6.+, IC1.3 (GND), J1.1 (3), J2.2, J3.P1 (1), J4.P1 (1), R2.2, SW3.A3 (3), SW3.B3 (3), U$2.GND1 (GND), U$2.GND2 (GND), U$2.GND3 (GND), U$2.GND4 (GND), U$2.GND5 (GND), U$2.GND6 (GND)
MULT_OUT: IC2.1 (OUT), IC2.2 (-IN), R4.1
unnamed: J1.2, J3.P2 (2)
unnamed: R3.2, U$2.V- (V--), U$2.V--
unnamed: D1.C, R3.1
unnamed: R1.2, U$2.V+ (V++), U$2.V++
unnamed: IC2.3 (+IN), IC2.5 (+IN), J3.P3 (3), R2.1
unnamed: SW2.A1 (1), W1.1
unnamed: SW2.B1 (1), W1.6
unnamed: SW2.B2 (2), SW3.B1 (1)
unnamed: SW2.A2 (2), SW3.A1 (1)
unnamed: J4.P3 (3), R4.2
unnamed: SW2.A3 (3), W1.3
unnamed: SW2.B3 (3), W1.4
unnamed: SW3.A2 (2), W1.2
unnamed: SW3.B2 (2), W1.5
unnamed: D2.A, R1.1
SGN_IN: IC2.6 (-IN), IC2.7 (OUT), W2.1
TST_TONE: J1.3 (1), W2.2

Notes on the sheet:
Voltage Regulation
AC/DC Switch
Signal/GND Switch
Signal Input

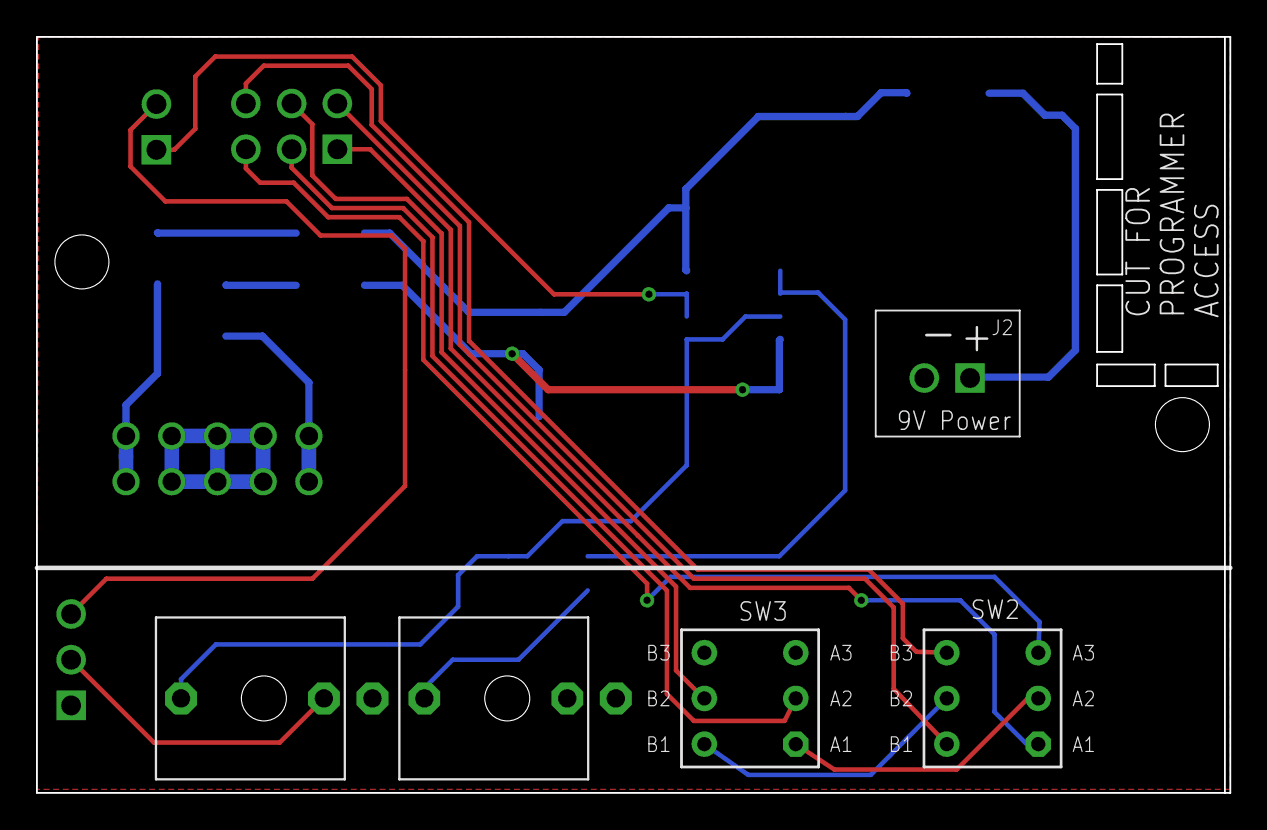
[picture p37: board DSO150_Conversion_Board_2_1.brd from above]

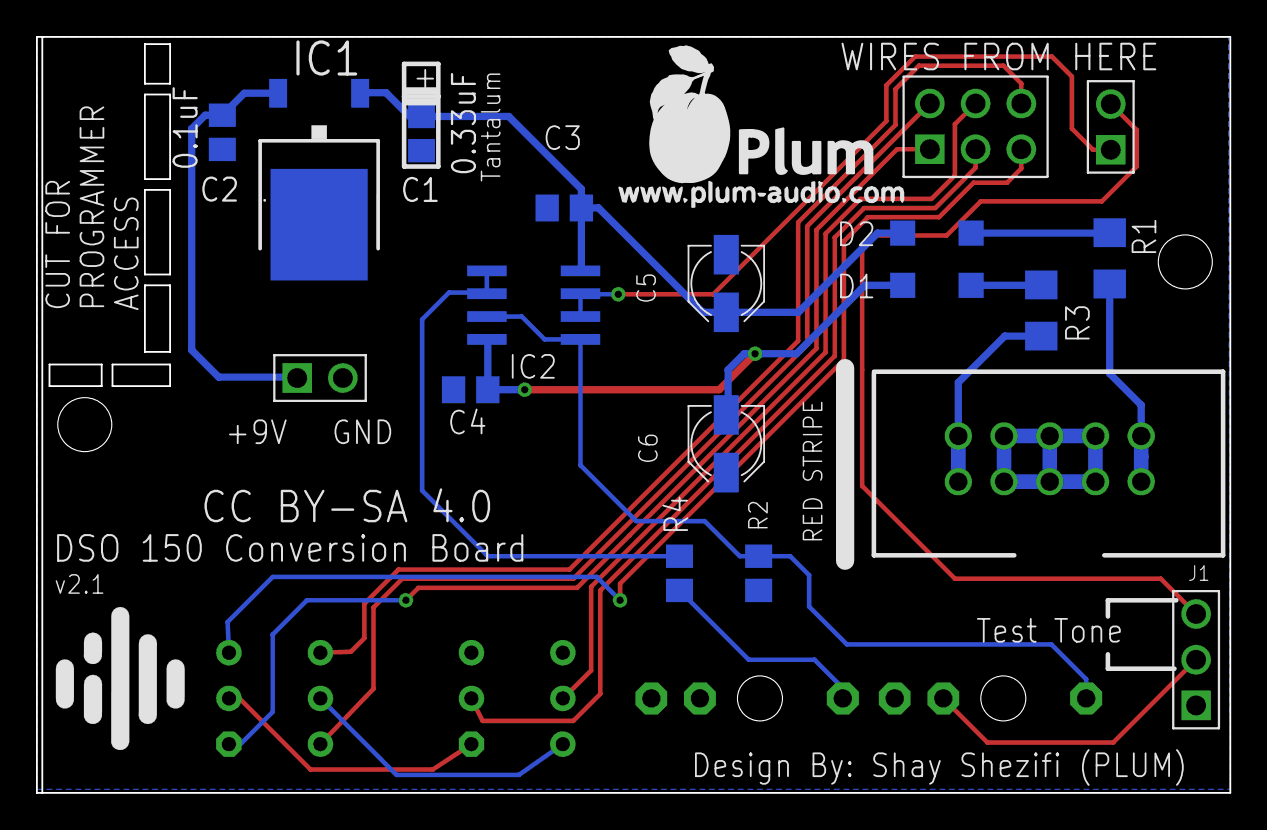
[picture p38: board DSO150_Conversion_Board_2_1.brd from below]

Board: 2 copper layers, 66.3 x 42.0 mm, 23 parts (19 on the bottom side), 22 nets.

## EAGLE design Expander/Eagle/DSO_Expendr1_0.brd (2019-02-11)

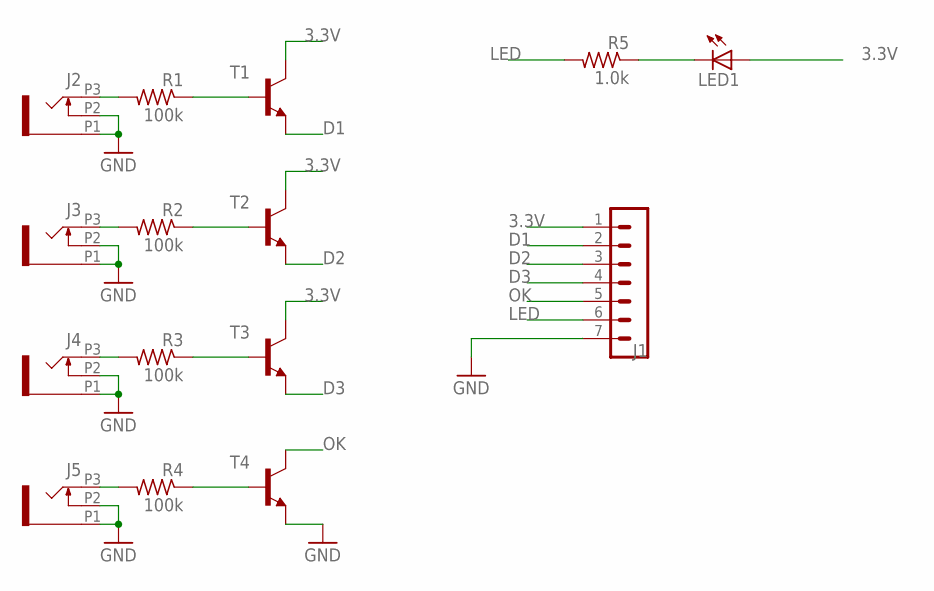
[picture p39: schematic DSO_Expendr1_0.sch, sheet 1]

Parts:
J1: MA07-1
J2, J3, J4, J5: OG-PJ301_PJ301_THONKICONN; OG-PJ301_WQP_PJ_301M6_NO_HOLE
LED1: LED_E; LED_1206
R1, R2, R3, R4: 100k; R0805
R5: 1.0k; R0805
T1, T2, T3, T4: MMBT3904LT1-NPN-SOT23-BEC; SOT23-BEC

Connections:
3.3V: J1.1, LED1.A, T1.C, T2.C, T3.C
D1: J1.2, T1.E
D2: J1.3, T2.E
D3: J1.4, T3.E
GND: J1.7, J2.P1 (1), J2.P2 (2), J3.P1 (1), J3.P2 (2), J4.P1 (1), J4.P2 (2), J5.P1 (1), J5.P2 (2), T4.E
LED: J1.6, R5.2
unnamed: J2.P3 (3), R1.2
unnamed: R1.1, T1.B
unnamed: J3.P3 (3), R2.2
unnamed: R2.1, T2.B
unnamed: J4.P3 (3), R3.2
unnamed: R3.1, T3.B
unnamed: J5.P3 (3), R4.2
unnamed: R4.1, T4.B
unnamed: LED1.C, R5.1
OK: J1.5, T4.C

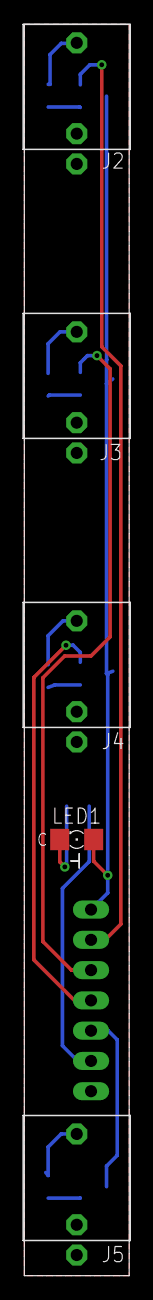
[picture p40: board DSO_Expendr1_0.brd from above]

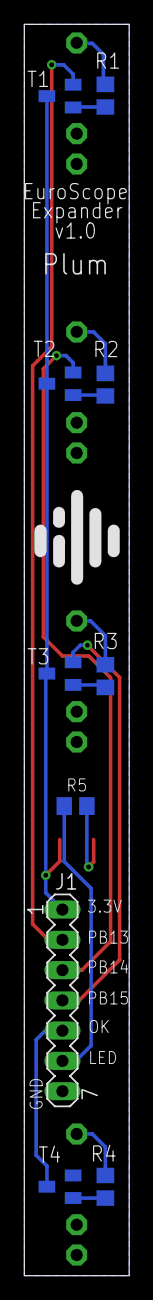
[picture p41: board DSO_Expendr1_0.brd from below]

Board: 2 copper layers, 8.8 x 105.0 mm, 15 parts (10 on the bottom side), 16 nets.

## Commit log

2019-02-11 EuroScope v1.0 Backup
    [DSO150_Conversion_Board_1.0.brd, DSO150_Conversion_Board_1.0.sch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]
2019-10-03 Updated BOM for v2.2
2019-10-03 Updated BOM v2.2

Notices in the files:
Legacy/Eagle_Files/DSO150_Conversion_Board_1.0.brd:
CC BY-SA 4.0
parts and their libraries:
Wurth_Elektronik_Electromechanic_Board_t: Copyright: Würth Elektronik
